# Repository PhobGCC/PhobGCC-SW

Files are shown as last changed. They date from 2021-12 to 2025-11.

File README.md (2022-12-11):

# PhobGCC

PhobGCC is an open-source Gamecube controller motherboard aiming to make an accessible and consistent controller. The key feature is the use of hall effect sensors instead of potentiometers, which eliminates a wear item. Additonally, it features notch calibration, digital snapback filtering, button remapping, and various trigger configurations.

If you are interested in making one, join the project Discord to ask questions and get the most up to date information: https://discord.gg/eNJ7xWMvxf

You can find all documentation here: https://github.com/PhobGCC/PhobGCC-doc

Board version 1.2:

Board version 1.2

Hall effect sensors:

Prototypes

Initial prototypes:

Prototypes

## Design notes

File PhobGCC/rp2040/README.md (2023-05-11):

To build PhobGCC for the RP2040:

1. Install the compiler toolchain as per the [Pico documentation](https://datasheets.raspberrypi.com/pico/getting-started-with-pico.pdf).
2. Git clone the `pico-sdk` repository from https://github.com/raspberrypi/pico-sdk
3. Check out the master branch.
4. Run `git submodule update --init` (omit `--init` if you're not doing it for the first time)
5. Export the `pico-sdk` directory as an environment variable `export PICO_SDK_PATH=[directory containing]/pico-sdk`
6. Clone the PhobGCC-SW repository.
7. Uncomment the appropriate `#include` line for your board in `../common/phobGCC.h`.
8. `cd` into the `PhobGCC/rp2040` subdirectory inside the `PhobGCC-SW` folder.
9. `mkdir build && cd build`
10. `cmake ..`
11. `make`?

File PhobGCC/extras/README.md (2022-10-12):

# Developer's Reference for Extras

This document (hopefully) intends to be a helpful guide for developers who wish to add additional features
to the PhobGCC called Extras that, while might be out of scope for normal operation, are officially supported 
and can be enabled manually by users if they uncomment out a `#define` directive and assign the Extra to one of
4 directional configurations.

# Overview

There is a loose framework for Extras written into the PhobGCC codebase for where to write your code, how to
hook your Extra into the main logic of the PhobGCC, and toggling / configuration. 

The general idea is that you write the logic for it as its own header file in the 'extras' folder while 
giving it its own namespace, write hooks to your code wrapped in `#ifdef`s in the main logic of the
PhobCC, then give function pointers for configuration and toggling your Extra to the PhobGCC 
Extras registration code in 'extras.h'.

We'll be going through all of these in this document.

# Data Structures

There's various data structures that you'll be utilizing as you write your Extra:

## Configuration Structures 

### ExtrasSlot
`ExtrasSlot` is an enum that is used as an index to reference which configuration direction slot an
Extra is using. You'll want to save a reference to which slot your configuration is using somewhere
in your Extra's header file since you'll need it to save your configuration settings.
```c++
enum ExtrasSlot{
	EXTRAS_UP,
	EXTRAS_DOWN,
	EXTRAS_LEFT,
	EXTRAS_RIGHT,
	EXTRAS_SIZE,
	EXTRAS_UNSET
};
```

### ExtrasConfig and IntOrFloat
`IntOrFloat` is a union that stores, well, either an `int` or a `float`. This is used as a part of the
Extras configuration struct `ExtrasConfig`, where each Extra gets 4 words worth of storage in the
EEPROM for storing and loading configuration settings. 
```c++
union IntOrFloat{
	int intValue;
	float floatValue;
};

struct ExtrasConfig{
	IntOrFloat config[4];
};
```

This is stored at the end of the `ControlConfig` struct which holds the general 
live configuration of the PhobGCC. 

```c++
/* ... */
	const int snapbackDefault;
	const float smoothingMin;
	const float smoothingMax;
	ExtrasConfig extras[EXTRAS_SIZE];
};
```

### Cardinals

`Cardinals` is a simple struct consisting of 4 variables, one for each direction. This is
passed in during the configuration of your Extra where each direction correlates to which
dpad button was pressed during the configuration button combo so you can handle what happens
with each direction accordingly.

```c++
struct Cardinals{
	uint8_t l : 1;
	uint8_t r : 1;
	uint8_t u : 1;
	uint8_t d : 1;
};
```

## EEPROM Setters

There's two functions you'll be using related to the configuration of your extra,
`setExtrasSettingInt` and `getExtrasSettingFloat`. These are used to write your Extra's
configuration to EEPROM so that they'll be automatically restored when the PhobGCC is
powered on after being unplugged.

```c++
void setExtrasSettingInt(const ExtrasSlot slot, const int offset, const int value);
void setExtrasSettingFloat(const ExtrasSlot slot, const int offset, const float value);
```

`slot` is the directional configuration that your Extra is 
  assigned to, you will have a reference to this in your
  Extra's header file. 
  
`offset` is a number 0-3 which determines which of the Extra's 
  4 configuration words your value will be written to. 
  
`value` is the value you're passing in to be written to EEPROM.

## Function Typedefs

There's two functions for toggling and configuring your Extra. The way to format these functions
are standardized with a `typedef` for each.

```c++
typedef bool(*ExtrasToggleFn)(IntOrFloat config[]);//Used for toggling extras
typedef void(*ExtrasConfigFn)(IntOrFloat config[], Cardinals dpad);//Used for configuring extras with the Dpad
```

### Toggling

The toggle function is called when the user is not in safe mode and uses the button combination:

* A + B + Both sticks pointed in the directional configuration

The toggle function takes in the configuration for your Extra so you can write and read from it, and returns
a `bool` that signals if you enabled (`true`) or disabled (`false`) your Extra. This return value
is used to freeze both sticks facing up-right or down-left as a visual indicator for the user
to determine if the Extra is now enabled or disabled. 

### Configuration

The config function is called when the user is not in safe mode and uses the button combination:

* A + Dpad (any direction) + Both sticks pointed in the directional configuration

The config function takes in the configuration for your Extra so you can write and read from it, but it 
also reads in the dpad as a `Cardinals` struct. In your config function, you can determine what happens depending
on what dpad button is currently being pressed.

# Writing the Hook

Depending on what you're trying to do, you'll write one or more hooks to your code's logic somewhere in
the main codebase of the PhobGCC. If you're creating some sort of new mapping or want to modify the control
sticks or analog trigger sliders, you'll probably write a hook to your code from `readSticks`. 

For example, here's the hook for the ESS Adapter Extra:

```c++
/* ... */
	//Clamp values from -125 to +125
	remappedAx = min(125, max(-125, remappedAx));
	remappedAy = min(125, max(-125, remappedAy));
	remappedCx = min(125, max(-125, remappedCx+controls.cXOffset));
	remappedCy = min(125, max(-125, remappedCy+controls.cYOffset));

	bool skipAHyst = false;
#ifdef EXTRAS_ESS
	//ESS adapter functionality for Ocarina of Time on WiiVC if enabled
	skipAHyst = ess::remap(&remappedAx, &remappedAy, controls.extras[ess::extrasEssConfigSlot].config);
#endif

	float hystVal = 0.3;
	//assign the remapped values to the button struct
	if(readA){
		if (!skipAHyst) {
/* ... */
```

Here I'm modifying the control sticks by passing them by reference to my Extra where they're
modified before logic returns back to here. 

Notice that I had to add this `skipAHyst` boolean outside of the `#ifdef`. You can add external
variables but only if needed. But ideally the only thing added is your `#ifdef` and a single
line to your header file in the 'extras' folder. 

More than likely you'll want to pass in the configuration options for your Extra as well since
the standard way to access an Extra's configuration is by passing it in from the hook where you'll
have access to `ControlConfig &controls` which contains `ExtrasConfig extras[EXTRAS_SIZE]`.

# Formatting your Extra's Header

Your Extra's header is where you have the freedom to do just about whatever you want with the
information you pass into it. There's a basic structure you'll want to follow however.

```c++
#ifndef EXTRAS_EXAMPLE_H
#define EXTRAS_EXAMPLE_H

namespace example {
  ExtrasSlot configSlot = EXTRAS_UNSET;
  
  // write your hook code here
  
  bool toggle(IntOrFloat config[]) {
    // toggle Extra and probably write enabled/disabled to EEPROM
  }

  void config(IntOrFloat config[], Cardinals dpad) {
    // config Extra and probably store it to EEPROM
  }
}

#endif //EXTRAS_EXAMPLE_H
```

Your Extra's config slot will be set from 'extras.h'. You'll use it if / when you need to save
your configuration by using the `setExtrasSettingInt` or `setExtrasSettingFloat` functions.

Again, the toggle and config functions need to follow the typdefs for `ExtrasToggleFn` and `ExtrasConfigFn`
since we'll be referencing them when we register the Extra in 'extras.h'.

# Adding your Extra to 'extras.h'

There's three things that need to be done to 'extras.h' when adding your Extra to the codebase:
* Adding a `#define` directive that can be uncommented to enable your Extra 
* Wraping the inclusion of your Extra's header file in `#ifdef`s
* Adding your Extra to the initialization function `extrasInit()`.

The first two are pretty straight forward, just add a new line under the existing Extras at the top
of the file and then just under that add your header file wrapped in the `#define` you made.

```c++
/* Plugins and extra features outside the normal scope of
 * the PhobGCC can be found here. Uncomment each #define
 * to include the features they provide in a build then
 * set the configuration slot it uses (if it needs configuration)
 * 
 */
//------------------------------------------------------
//#define EXTRAS_ESS
//#define EXTRAS_EXAMPLE <--- your new Extra
//------------------------------------------------------

#ifdef EXTRAS_ESS
#include "ess.h"
#endif

// your new Extra
#ifdef EXTRAS_EXAMPLE
#include "example.h" 
#endif
```

For the third one, you can essentially copy and paste an 
existing `#ifdef`'d blocks and modify it as needed. 

You should not add anything extra to these lines, only modify
the text and change the function references to point to the 
ones in your Extra. 

`extrasConfigAssign` takes in 3 parameters: 

* `slot` is the directional configuration slot that the users sets.
* `toggleFn` is the function pointer to your Extra's toggle function.
* `configFn` is the function pointer to your Extra's config function.

Either or both function pointers can be safely set to `NULL` if not used.

```c++
void extrasInit() {
	/*----------------------------------------------------------
	 * Configuration slots for extras, the available options are:
	 *	- EXTRAS_UP
	 *	- EXTRAS_DOWN
	 *	- EXTRAS_LEFT
	 *	- EXTRAS_RIGHT
	 * Make sure to set the slot from EXTRAS_UNSET to one of the
	 * above for the extras below if applicable!
	 */

#ifdef EXTRAS_ESS
	//-----------------------------------------
	ess::extrasEssConfigSlot = EXTRAS_UNSET;
	//-----------------------------------------
	Serial.println("Extra: Enabling ESS functionality...");
	extrasConfigAssign(ess::extrasEssConfigSlot, ess::toggle, NULL);
#endif

// your new Extra
#ifdef EXTRAS_EXAMPLE
	//-----------------------------------------
	example::configSlot = EXTRAS_UNSET;
	//-----------------------------------------
	Serial.println("Extra: Enabling Example functionality...");
	extrasConfigAssign(example::configSlot, example::toggle, example::config);
#endif

}
```

# Closing Comments

This is about it with regards to developing Extras for the PhobGCC firmware. If you have any questions
about how something works or need help figuring out how to format your code, or anything else related
to developing Extras, please stop by the Discord and ask for help. 

[PhobGCC Discord](https://discord.gg/yrpUu7mgzm)

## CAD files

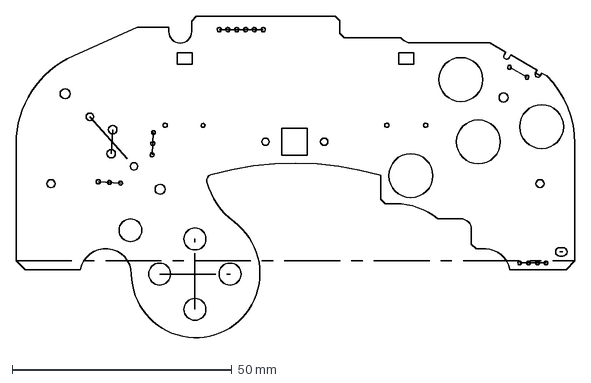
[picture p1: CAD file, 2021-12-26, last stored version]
PCB/Graphics/Board Outline.DXF
127.0 x 74.1 mm

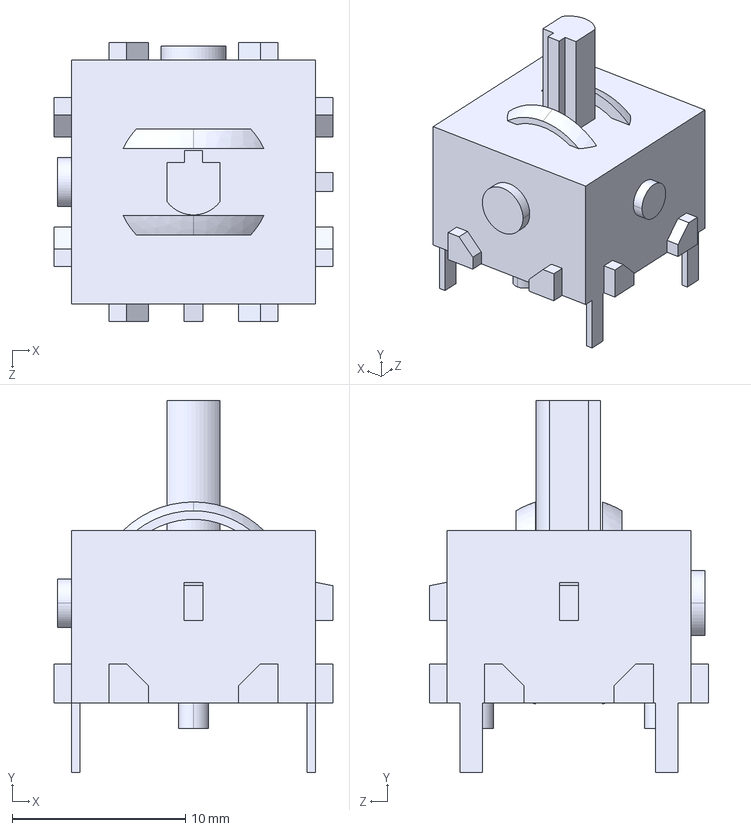
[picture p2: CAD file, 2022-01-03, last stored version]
PCB/Models/t2 Stickbox.STEP
16.1 x 21.4 x 16.1 mm

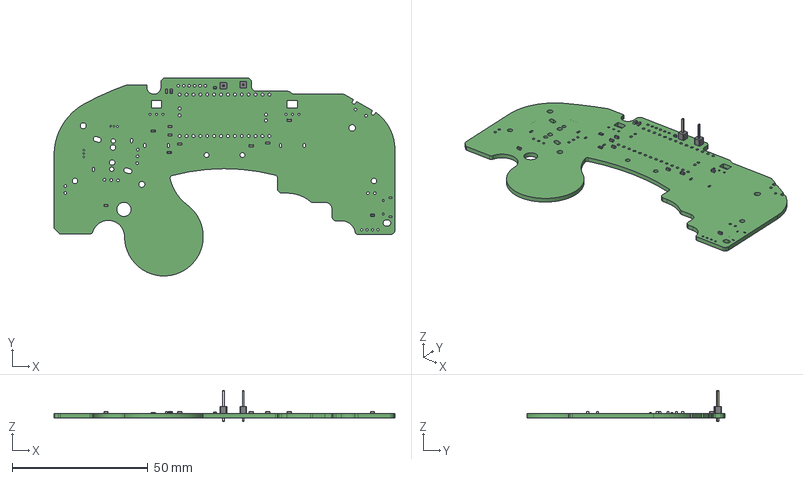
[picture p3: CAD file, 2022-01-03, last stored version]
PCB/PhobGCC.step
125.5 x 72.9 x 11.5 mm
Pin_Header_Straight_1x02_Pitch2.54mm x 2

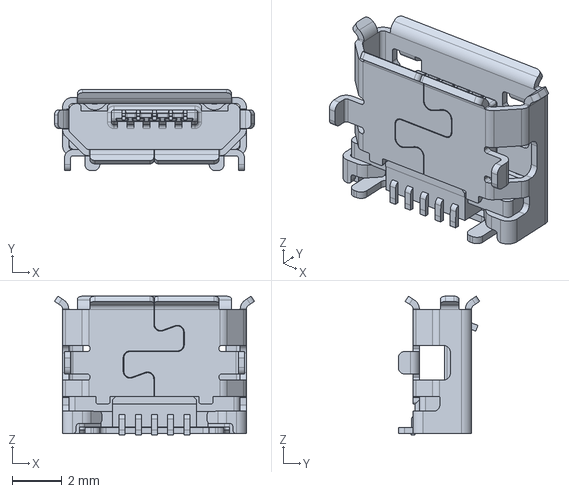
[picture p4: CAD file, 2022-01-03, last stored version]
PCB/Models/10118194c.step
8.05 x 3.27 x 5.58 mm

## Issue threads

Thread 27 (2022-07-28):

add optional auto-wake

CarVac, 2022-07-28:
it should reset any time you reset or calibrate

CarVac, 2022-08-10:
Implemented here https://github.com/PhobGCC/PhobGCC-SW/commit/e94b27e09e99a4c4f145899286b73ea4027d42db

Closed 2022-08-13.

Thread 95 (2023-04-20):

feature request: trigger trick mode

CarVac, 2023-04-20:
Should it be an offset from the startup slider position, or a fixed offset from 0 volts?

Dunno. TBD.

trstruth, 2023-09-06:
+1, would love to see something like this!

carafelix, 2023-12-01:
```.triggerConfigMax = 7,```
and
```C
case 7: //Modify Analog Trigger Starting point
			tempBtn.Ra = (uint8_t) readRa(pin, controls.rTrigInitial, 1) * shutoffRa;

			if(tempBtn.Ra < controls.rTriggerOffset){
				tempBtn.Ra = (uint8_t) 0;
			}
			break;
			```

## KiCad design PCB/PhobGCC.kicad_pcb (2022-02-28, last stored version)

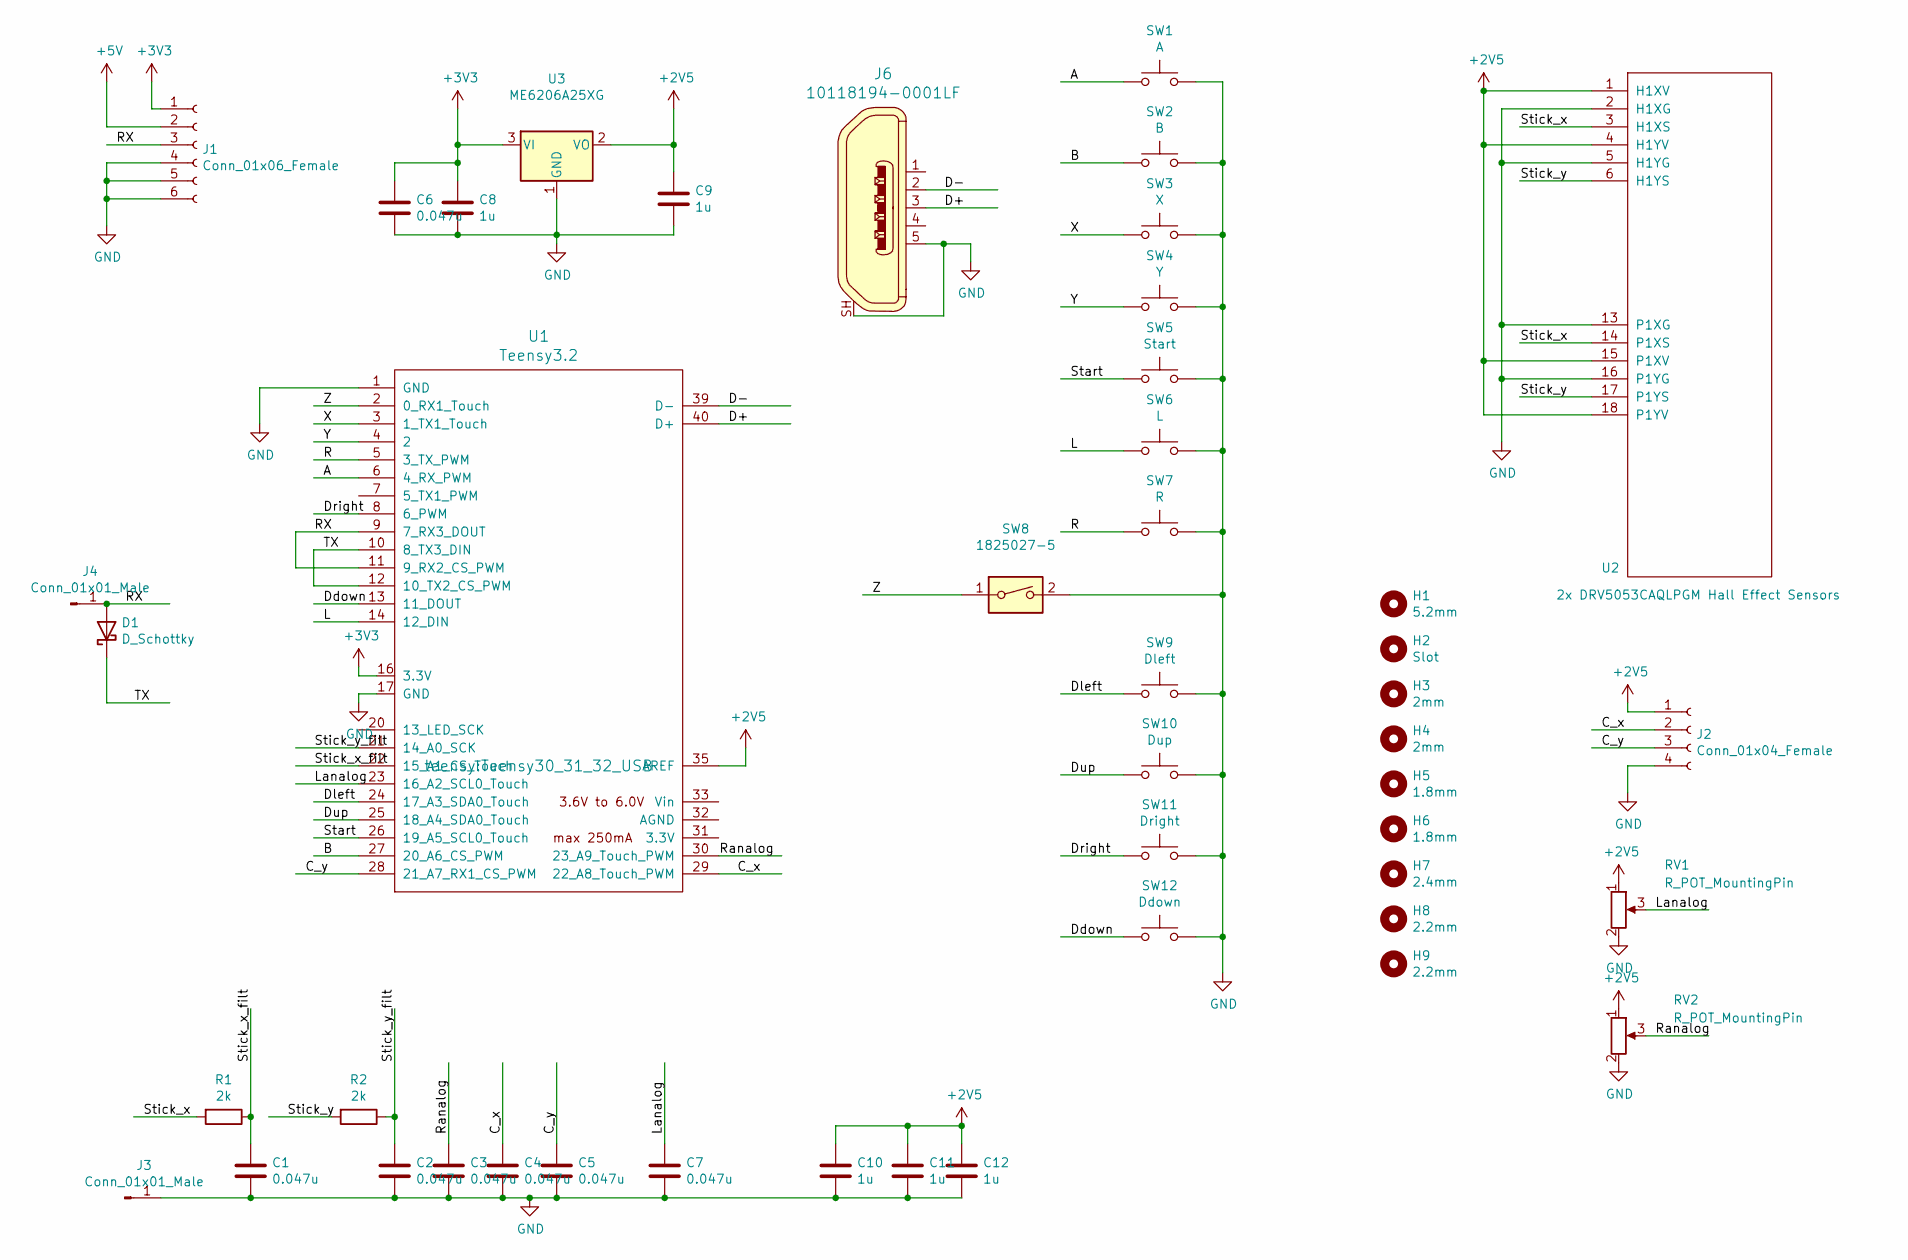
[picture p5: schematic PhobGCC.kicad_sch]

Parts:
C1, C2, C3, C4, C5, C6, C7: 0.047u; C_0603_HandSoldering; MPN 0603B222K500NT; LCSC C1604
C8, C9, C10, C11, C12: 1u; C_0603_HandSoldering; MPN CL10A105KB8NNNC; LCSC C15849
D1: D_Schottky; D_SOD-523_large_pads; Manufacturer PN SDM03U40-7; LCSC C151333
H1: 5.2mm; MountingHole_5.2mm
H2: Slot
H3, H4: 2mm; MountingHole_2.0mm
H5, H6: 1.8mm; MountingHole_1.8mm
H7: 2.4mm; MountingHole_2.4mm
H8, H9: 2.2mm; MountingHole_2.2mm
J1: Conn_01x06_Female; GCC_Header_Straight_1x06_Pitch2.00mm
J2: Conn_01x04_Female; Pin_Header_Straight_1x04_Pitch2.00mm
J3, J4: Conn_01x01_Male; PinHeader_1x01_P2.54mm_Vertical
J6: 10118194-0001LF; USB_Micro_B_Female_10118194-0001LF; MPN 10118194-0001LF; Digi-Key_PN 609-4618-1-ND
R1: 2k; R_0603_1608Metric; Manufacturer PN 0603WAF1002T5ECopy; LCSC C25804
R2: 2k; R_0603_1608Metric; MPN 0603WAF1002T5E; LCSC C25804
RV1, RV2: R_POT_MountingPin; GCC_Slider
SW1: A; ABXY_layout_small_mask
SW2: B; ABXY_layout_small_mask
SW3: X; ABXY_layout_small_mask
SW4: Y; ABXY_layout_small_mask
SW5: Start; Start_Contact
SW6: L; Pin_Header_Straight_1x02_Pitch2.54mm
SW7: R; Pin_Header_Straight_1x02_Pitch2.54mm
SW8: 1825027-5; Z_Switch_Edge
SW9: Dleft; Dpad_Contact
SW10: Dup; Dpad_Contact
SW11: Dright; Dpad_Contact
SW12: Ddown; Dpad_Contact
U1: Teensy3.2; Teensy30_31_32_USB
U2: 2x DRV5053CAQLPGM Hall Effect Sensors; GCC_Stickbox_2
U3: ME6206A25XG; SOT-23_Handsoldering; MPN ME6206A25XG; LCSC C236704

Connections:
+2V5: C9.1, C10.1, C11.1, C12.1, J2.1, RV1.1 (V+), RV2.1 (V+), U1.35 (AREF), U2.1 (H1XV), U2.4 (H1YV), U2.15 (P1XV), U2.18 (P1YV), U3.2 (VO)
+3V3: C6.1, C8.1, J1.1, U1.16 (3.3V), U3.3 (VI)
+5V: J1.2
/A: SW1.1, U1.6 (4_RX_PWM)
/B: SW2.1, U1.27 (20_A6_CS_PWM)
/C_x: C4.1, J2.2, U1.29 (22_A8_Touch_PWM)
/C_y: C5.1, J2.3, U1.28 (21_A7_RX1_CS_PWM)
/D+: J6.3, U1.40 (D+)
/D-: J6.2, U1.39 (D-)
/Ddown: SW12.1, U1.13 (11_DOUT)
/Dleft: SW9.1, U1.24 (17_A3_SDA0_Touch)
/Dright: SW11.1, U1.8 (6_PWM)
/Dup: SW10.1, U1.25 (18_A4_SDA0_Touch)
/L: SW6.1, U1.14 (12_DIN)
/Lanalog: C7.1, RV1.3 (Signal), U1.23 (16_A2_SCL0_Touch)
/R: SW7.1, U1.5 (3_TX_PWM)
/RX: D1.2 (A), J1.3, J4.1, U1.9 (7_RX3_DOUT), U1.11 (9_RX2_CS_PWM)
/Ranalog: C3.1, RV2.3 (Signal), U1.30 (23_A9_Touch_PWM)
/Start: SW5.1, U1.26 (19_A5_SCL0_Touch)
/Stick_x: R1.2, U2.3 (H1XS), U2.14 (P1XS)
/Stick_x_filt: C1.1, R1.1, U1.22 (15_A1_CS_Touch)
/Stick_y: R2.2, U2.6 (H1YS), U2.17 (P1YS)
/Stick_y_filt: C2.1, R2.1, U1.21 (14_A0_SCK)
/TX: D1.1 (K), U1.10 (8_TX3_DIN), U1.12 (10_TX2_CS_PWM)
/X: SW3.1, U1.3 (1_TX1_Touch)
/Y: SW4.1, U1.4 (2)
/Z: SW8.1, U1.2 (0_RX1_Touch)
GND: C1.2, C2.2, C3.2, C4.2, C5.2, C6.2, C7.2, C8.2, C9.2, C10.2, C11.2, C12.2, J1.4, J1.5, J1.6, J2.4, J3.1, J6.5, J6.SH, RV1.2 (GND), RV2.2 (GND), SW1.2, SW2.2, SW3.2, SW4.2, SW5.2, SW6.2, SW7.2, SW8.2, SW9.2, SW10.2, SW11.2, SW12.2, U1.1 (GND), U1.17 (GND), U2.2 (H1XG), U2.5 (H1YG), U2.13 (P1XG), U2.16 (P1YG), U3.1 (GND)

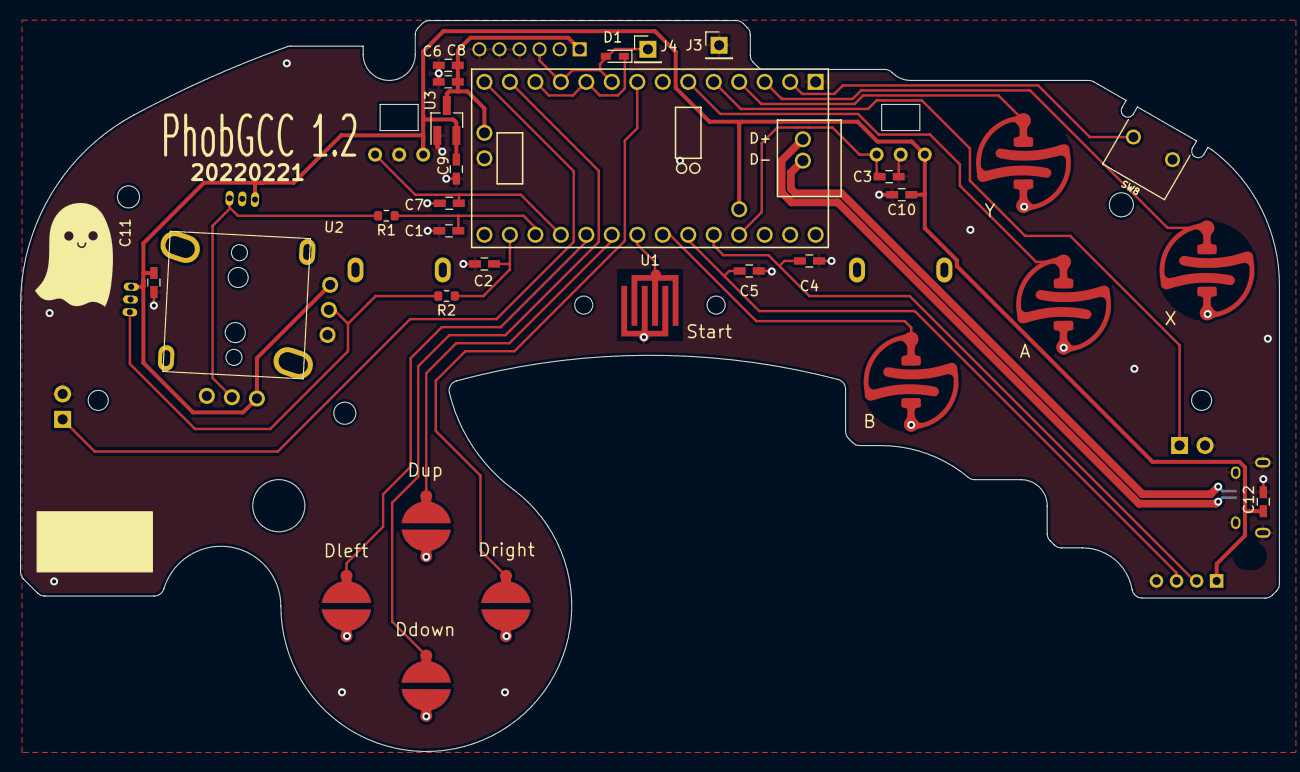
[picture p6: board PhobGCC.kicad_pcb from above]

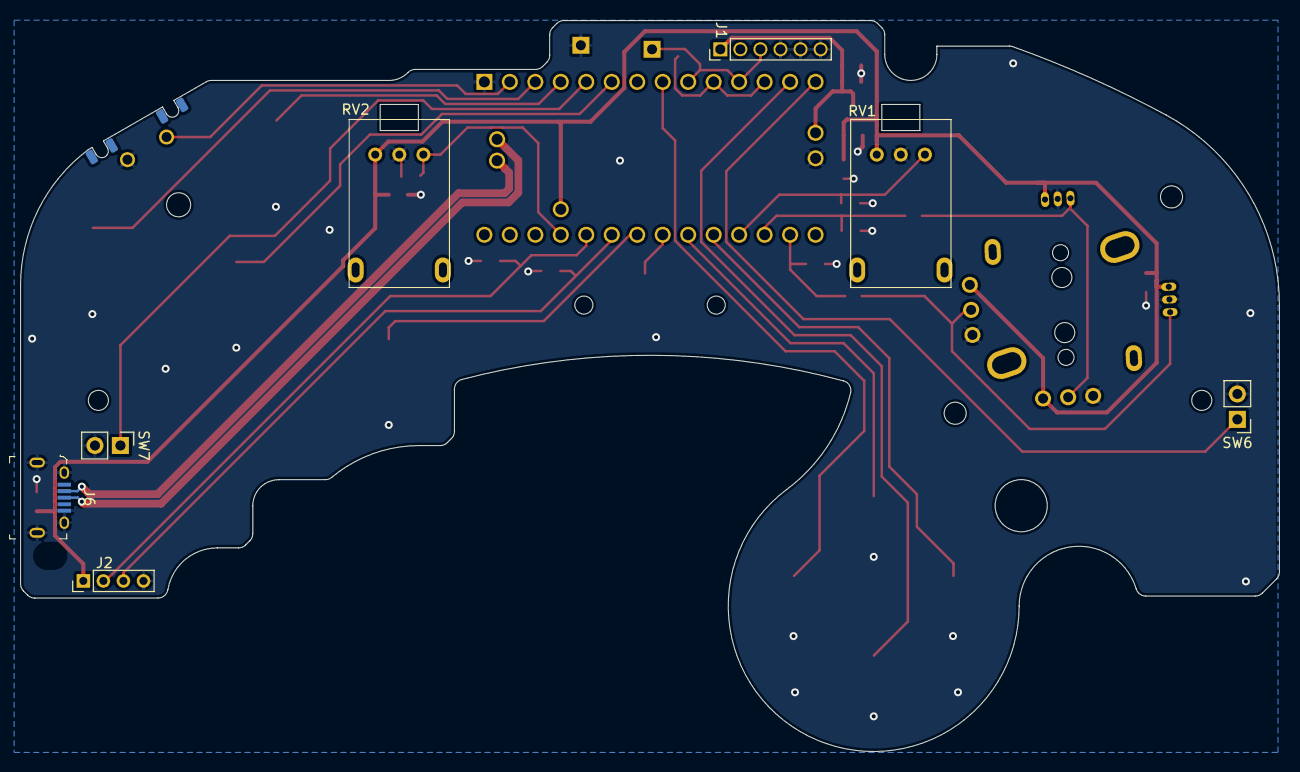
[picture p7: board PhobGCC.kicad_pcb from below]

Board: 2 copper layers, 125.5 x 72.9 mm, 46 parts (7 on the bottom side), 27 nets.

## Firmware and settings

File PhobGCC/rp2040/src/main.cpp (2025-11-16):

#include "pico/stdlib.h"
#include "pico/bootrom.h"
#include "pico/multicore.h"
#include "hardware/timer.h"
#include "hardware/pwm.h"

#include "phobGCC.h"
#include "comms/joybus.hpp"
#include "cvideo.h"
#include "cvideo_variables.h"
#include "hardware/clocks.h"

volatile bool _videoOut = false;
//Variables used by PhobVision to communicate with the event loop core
volatile bool _sync = false;
volatile uint8_t _pleaseCommit = 0;//255 = redraw please
int _currentCalStep = -1;//-1 means not calibrating
int _currentRemapStep = -1;//-1 means not remapping
bool _currentlyRaw = false;
DataCapture _dataCapture;

//This gets called by the comms library
GCReport __no_inline_not_in_flash_func(buttonsToGCReport)() {
	GCReport report = {{
		.a       = _btn.A,
		.b       = _btn.B,
		.x       = _btn.X,
		.y       = _btn.Y,
		.start   = _btn.S,
		.pad0    = 0,
		.dLeft   = _btn.Dl,
		.dRight  = _btn.Dr,
		.dDown   = _btn.Dd,
		.dUp     = _btn.Du,
		.z       = _btn.Z,
		.r       = _btn.R,
		.l       = _btn.L,
		.pad1    = 1,
		.xStick  = _btn.Ax,
		.yStick  = _btn.Ay,
		.cxStick = _btn.Cx,
		.cyStick = _btn.Cy,
		.analogL = _btn.La,
		.analogR = _btn.Ra
	}};
	return report;
}

void second_core() {

	gpio_set_function(_pinLED, GPIO_FUNC_PWM);
	uint slice_num = pwm_gpio_to_slice_num(_pinLED);
	pwm_set_wrap(slice_num, 255);
	pwm_set_chan_level(slice_num, PWM_CHAN_B, 25);
	pwm_set_enabled(slice_num, true);

	extrasInit();


	while(true) { //main event loop
		//Set up persistent storage for calibration
		static float tempCalPointsX[_noOfCalibrationPoints];
		static float tempCalPointsY[_noOfCalibrationPoints];
		static WhichStick whichStick = ASTICK;
		static NotchStatus notchStatus[_noOfNotches];
		static float notchAngles[_noOfNotches];
		static float measuredNotchAngles[_noOfNotches];
		static bool advanceCal = false;
		static bool undoCal = false;


		//when requested by the other core, commit the settings
		if(_pleaseCommit != 0) {
			if(_pleaseCommit == 1) {
				_pleaseCommit = 0;
				recomputeGains(_controls, _gains, _normGains);
				commitSettings();
			} else if(_pleaseCommit == 2) {
				_pleaseCommit = 0;
				resetDefaults(SOFT, _controls, _gains, _normGains, _aStickParams, _cStickParams);
			} else if(_pleaseCommit == 3) {
				_pleaseCommit = 0;
				resetDefaults(HARD, _controls, _gains, _normGains, _aStickParams, _cStickParams);
			} else if(_pleaseCommit == 4) {
				//Advance cal, A-stick
				_pleaseCommit = 255;
				whichStick = ASTICK;
				if(_currentCalStep == -1) {
					_currentCalStep++;
				}
				calibrationAdvance(_controls, _currentCalStep, whichStick, tempCalPointsX, tempCalPointsY, undoCal, notchAngles, notchStatus, measuredNotchAngles, _aStickParams, _cStickParams);
			} else if(_pleaseCommit == 5) {
				//Advance cal, C-stick
				_pleaseCommit = 255;
				whichStick = CSTICK;
				if(_currentCalStep == -1) {
					_currentCalStep++;
				}
				calibrationAdvance(_controls, _currentCalStep, whichStick, tempCalPointsX, tempCalPointsY, undoCal, notchAngles, notchStatus, measuredNotchAngles, _aStickParams, _cStickParams);
			} else if(_pleaseCommit == 6) {
				//undo cal
				_pleaseCommit = 255;
				calibrationUndo(_currentCalStep, whichStick, notchStatus);
			} else if(_pleaseCommit == 7) {
				//skip cal (might not actually get used?) (it's available but not shown)
				_pleaseCommit = 255;
				calibrationSkipMeasurement(_currentCalStep, whichStick, tempCalPointsX, tempCalPointsY, notchStatus, notchAngles, measuredNotchAngles, _aStickParams, _cStickParams, _controls);
			} else if(_pleaseCommit == 8) {
				_pleaseCommit = 0;
				_rumblePower = calcRumblePower(_controls.rumble);
				//rumble for 0.3 seconds
				pwm_set_gpio_level(_pinBrake, 0);
				pwm_set_gpio_level(_pinRumble, _rumblePower);
				int startTime = millis();
				int delta = 0;
				while(delta < 300) {
					delta = millis() - startTime;
				}
				pwm_set_gpio_level(_pinRumble, 0);
				pwm_set_gpio_level(_pinBrake, 255);
			} else if(_pleaseCommit == 9) {
				switch(_dataCapture.mode) {
					//make sure that we can write 200 things in a1 (clobbering a2) for longer recording
					//this is used for single-axis recording
					static_assert(&_dataCapture.a1[100] == &_dataCapture.a2[0]);
					static_assert(&_dataCapture.a1Unfilt[100] == &_dataCapture.a2Unfilt[0]);

					case CM_REACTION:
						//this expects that you initialize data capture by setting delay to 0
						_dataCapture.delay++;
						if(
								//_btn.arr[0] & 0b11110000 ||//abxy
								//_btn.arr[1] & 0b11111110 ||//dpad, lrz
								_btn.arr[0] & 0b00001111 ||//abxy
								_btn.arr[1] & 0b01111111 ||//dpad, lrz
								max(max(abs(int(_btn.Ax)-127), abs(int(_btn.Ay)-127)),
									max(abs(int(_btn.Cx)-127), abs(int(_btn.Cy)-127))) >= _dataCapture.stickThresh ||
								max(_btn.La, _btn.Ra) >= _dataCapture.triggerThresh) {
							_dataCapture.done = true;
							_pleaseCommit = 255;//end capture and display
						}
						break;
					case CM_STICK_RISE2:
						//100 points of 2-axis data
						//this begins capturing data immediately in a rolling buffer,
						//and on detecting a rising edge it begins recording
						//this records the starting point only the first time, then it sets begin
						static int x0;
						static int y0;

						if(!_dataCapture.begin && !_dataCapture.done) {
							_dataCapture.begin = true;
							_dataCapture.done = false;
							_dataCapture.startIndex = 0;
							_dataCapture.endIndex = 255;//when it triggers, we freeze startIndex and start counting up here
							if(_dataCapture.captureStick == ASTICK) {
								x0 = _raw.axUnfiltered;
								y0 = _raw.ayUnfiltered;
								_dataCapture.a1[_dataCapture.startIndex] = _btn.Ax;
								_dataCapture.a2[_dataCapture.startIndex] = _btn.Ay;
								_dataCapture.a1Unfilt[_dataCapture.startIndex] = (uint8_t) (_raw.axUnfiltered+_floatOrigin);
								_dataCapture.a2Unfilt[_dataCapture.startIndex] = (uint8_t) (_raw.ayUnfiltered+_floatOrigin);
							} else {
								x0 = _raw.cxUnfiltered;
								y0 = _raw.cyUnfiltered;
								_dataCapture.a1[_dataCapture.startIndex] = _btn.Cx;
								_dataCapture.a2[_dataCapture.startIndex] = _btn.Cy;
								_dataCapture.a1Unfilt[_dataCapture.startIndex] = (uint8_t) (_raw.cxUnfiltered+_floatOrigin);
								_dataCapture.a2Unfilt[_dataCapture.startIndex] = (uint8_t) (_raw.cyUnfiltered+_floatOrigin);
							}
							//                                                                   syxba                       lrz
							_dataCapture.abxyszrl[_dataCapture.startIndex] = (_btn.arr[0] & 0b00011111) | ((_btn.arr[1] & 0b01110000) << 1);
						} else {
							if(_dataCapture.endIndex == 255) {
								//not triggered yet
								//increment startIndex
								_dataCapture.startIndex = (_dataCapture.startIndex+1) % 100;
								//record
								if(_dataCapture.captureStick == ASTICK) {
									_dataCapture.a1[_dataCapture.startIndex] = _btn.Ax;
									_dataCapture.a2[_dataCapture.startIndex] = _btn.Ay;
									_dataCapture.a1Unfilt[_dataCapture.startIndex] = (uint8_t) (_raw.axUnfiltered+_floatOrigin);
									_dataCapture.a2Unfilt[_dataCapture.startIndex] = (uint8_t) (_raw.ayUnfiltered+_floatOrigin);
									//if it's not triggered, do nothing further
									//if it's triggered, set endIndex to startIndex+1
									int diffX = abs(int(_raw.axUnfiltered) - x0);
									int diffY = abs(int(_raw.ayUnfiltered) - y0);
									if(diffX > _dataCapture.stickThresh || diffY > _dataCapture.stickThresh) {
										_dataCapture.endIndex = (_dataCapture.startIndex+1) % 100;
									}
								} else {
									_dataCapture.a1[_dataCapture.startIndex] = _btn.Cx;
									_dataCapture.a2[_dataCapture.startIndex] = _btn.Cy;
									_dataCapture.a1Unfilt[_dataCapture.startIndex] = (uint8_t) (_raw.cxUnfiltered+_floatOrigin);
									_dataCapture.a2Unfilt[_dataCapture.startIndex] = (uint8_t) (_raw.cyUnfiltered+_floatOrigin);
									//if it's not triggered, do nothing further
									//if it's triggered, set endIndex to startIndex+1
									int diffX = abs(int(_raw.cxUnfiltered) - x0);
									int diffY = abs(int(_raw.cyUnfiltered) - y0);
									if(diffX > _dataCapture.stickThresh || diffY > _dataCapture.stickThresh) {
										_dataCapture.endIndex = (_dataCapture.startIndex+1) % 100;
									}
								}
								//                                                                   syxba                       lrz
								_dataCapture.abxyszrl[_dataCapture.startIndex] = (_btn.arr[0] & 0b00011111) | ((_btn.arr[1] & 0b01110000) << 1);
							} else if(_dataCapture.endIndex != _dataCapture.startIndex) {
								//triggered
								//record
								if(_dataCapture.captureStick == ASTICK) {
									_dataCapture.a1[_dataCapture.endIndex] = _btn.Ax;
									_dataCapture.a2[_dataCapture.endIndex] = _btn.Ay;
									_dataCapture.a1Unfilt[_dataCapture.endIndex] = (uint8_t) (_raw.axUnfiltered+_floatOrigin);
									_dataCapture.a2Unfilt[_dataCapture.endIndex] = (uint8_t) (_raw.ayUnfiltered+_floatOrigin);
								} else {
									_dataCapture.a1[_dataCapture.endIndex] = _btn.Cx;
									_dataCapture.a2[_dataCapture.endIndex] = _btn.Cy;
									_dataCapture.a1Unfilt[_dataCapture.endIndex] = (uint8_t) (_raw.cxUnfiltered+_floatOrigin);
									_dataCapture.a2Unfilt[_dataCapture.endIndex] = (uint8_t) (_raw.cyUnfiltered+_floatOrigin);
								}
								//                                                                 syxba                       lrz
								_dataCapture.abxyszrl[_dataCapture.endIndex] = (_btn.arr[0] & 0b00011111) | ((_btn.arr[1] & 0b01110000) << 1);
								//increment endIndex
								_dataCapture.endIndex = (_dataCapture.endIndex+1) % 100;
							} else {
								//done
								_dataCapture.done = true;
								_pleaseCommit = 255;//end capture and display
							}
						}
						break;
					case CM_STICK_RISE:
						//200 points of single-axis data
						//based on the raw unfiltered values hitting >= 23
						//it should record for 150 ms after detection (saving 50 from before detection)

						//prep
						//expect data to be prepped already
						//begin = false
						//triggered = false
						//done = false
						//startIndex = 0
						//endIndex = 0

						//record data continuously if not done
						//actually, if it's done, it should never reach this
						if(_dataCapture.captureStick == ASTICK && _dataCapture.whichAxis == XAXIS) {
							_dataCapture.a1[_dataCapture.endIndex] = _btn.Ax;
							_dataCapture.a1Unfilt[_dataCapture.endIndex] = (uint8_t) (_raw.axUnfiltered+_floatOrigin);
						} else if(_dataCapture.captureStick == ASTICK && _dataCapture.whichAxis == YAXIS) {
							_dataCapture.a1[_dataCapture.endIndex] = _btn.Ay;
							_dataCapture.a1Unfilt[_dataCapture.endIndex] = (uint8_t) (_raw.ayUnfiltered+_floatOrigin);
						} else if(_dataCapture.captureStick == CSTICK && _dataCapture.whichAxis == XAXIS) {
							_dataCapture.a1[_dataCapture.endIndex] = _btn.Cx;
							_dataCapture.a1Unfilt[_dataCapture.endIndex] = (uint8_t) (_raw.cxUnfiltered+_floatOrigin);
						} else {//if(_dataCapture.captureStick == CSTICK && _dataCapture.whichAxis == YAXIS)
							_dataCapture.a1[_dataCapture.endIndex] = _btn.Cy;
							_dataCapture.a1Unfilt[_dataCapture.endIndex] = (uint8_t) (_raw.cyUnfiltered+_floatOrigin);
						}

						//check for initial waiting state
						//in this case, we want the stick's raw value to be out of the deadzone
						if(!_dataCapture.begin && !_dataCapture.done) {
							if(_dataCapture.captureStick == ASTICK && _dataCapture.whichAxis == XAXIS) {
								if(fabs(_raw.axUnfiltered) >= 23) {
									_dataCapture.begin = true;
									_dataCapture.startIndex = (_dataCapture.endIndex+150) % 200;
								}
							} else if(_dataCapture.captureStick == ASTICK && _dataCapture.whichAxis == YAXIS) {
								if(fabs(_raw.ayUnfiltered) >= 23) {
									_dataCapture.begin = true;
									_dataCapture.startIndex = (_dataCapture.endIndex+150) % 200;
								}
							} else if(_dataCapture.captureStick == CSTICK && _dataCapture.whichAxis == XAXIS) {
								if(fabs(_raw.cxUnfiltered) >= 23) {
									_dataCapture.begin = true;
									_dataCapture.startIndex = (_dataCapture.endIndex+150) % 200;
								}
							} else {//if(_dataCapture.captureStick == CSTICK && _dataCapture.whichAxis == YAXIS)
								if(fabs(_raw.cyUnfiltered) >= 23) {
									_dataCapture.begin = true;
									_dataCapture.startIndex = (_dataCapture.endIndex+150) % 200;
								}
							}
						}


						//stop if done
						if(_dataCapture.begin && _dataCapture.startIndex == _dataCapture.endIndex) {
							//calculate the dashback chance
							//see how many ms were spent in the tilt zone, and divide by 1 frame duration
							int counter = 0;
							for(int i = 0; i < 200; i++) {
								if(fabs(_dataCapture.a1[(i+_dataCapture.startIndex+1) % 200]-_intOrigin) >= 23) {
									if(fabs(_dataCapture.a1[(i+_dataCapture.startIndex+1) % 200]-_intOrigin) >= 64) {
										break;
									}
									counter++;
								}
							}
							_dataCapture.percents[0] = fmax(0, (1 - (counter/16.666667f))*100);

							//calculate ucf dashback percent
							//ucf dashback has a two frame window but the stick must have moved 75 units
							counter = 0;
							//try each poll offset; err on the short side
							for(int offset = 0; offset < 16; offset++) {
								for(int i = offset; i < (200-32); i += 16) {
									bool dashback = false;
									const int waitIndex = (i + _dataCapture.startIndex+1) % 200;
									const int vanIndex = (i + _dataCapture.startIndex+1+16) % 200;
									const int ucfIndex = (i + _dataCapture.startIndex+1+32) % 200;
									const int waitData = abs(_dataCapture.a1[waitIndex] - _intOrigin);
									const int vanData = abs(_dataCapture.a1[vanIndex] - _intOrigin);
									const int ucfData = abs(_dataCapture.a1[ucfIndex] - _intOrigin);
									if(waitData < 23 && vanData >= 64) {
										dashback = true;
									}
									if(waitData < 23 && ucfData >= 64 && ucfData-waitData > 75) {
										dashback = true;
									}
									if(dashback) {
										counter++;
									}
								}
							}
							const float ucfDB = fmax(0, fmin(100, counter*100/16.0f));
							//never want ucf % to read less than vanilla
							//it would sometimes be like 4% lower, because we were conservative here
							_dataCapture.percents[1] = fmax(_dataCapture.percents[0], ucfDB);

							//clean up
							_dataCapture.done = true;
							_pleaseCommit = 255;//end capture and display
						}

						//advance to next index to record
						_dataCapture.endIndex = (_dataCapture.endIndex+1) % 200;
						break;
					case CM_STICK_FALL:
						//single-axis
						//based on the raw unfiltered values falling from >70 to 0 in <30 ms
						//it should record for 150 ms after detection (saving 50 from before detection)

						//prep
						//expect data to be prepped already
						//begin = false
						//triggered = false
						//done = false
						//startIndex = 0
						//endIndex = 0

						//record data continuously if not done
						//actually, if it's done, it should never reach this
						if(_dataCapture.captureStick == ASTICK && _dataCapture.whichAxis == XAXIS) {
							_dataCapture.a1[_dataCapture.endIndex] = _btn.Ax;
							_dataCapture.a1Unfilt[_dataCapture.endIndex] = (uint8_t) (_raw.axUnfiltered+_floatOrigin);
						} else if(_dataCapture.captureStick == ASTICK && _dataCapture.whichAxis == YAXIS) {
							_dataCapture.a1[_dataCapture.endIndex] = _btn.Ay;
							_dataCapture.a1Unfilt[_dataCapture.endIndex] = (uint8_t) (_raw.ayUnfiltered+_floatOrigin);
						} else if(_dataCapture.captureStick == CSTICK && _dataCapture.whichAxis == XAXIS) {
							_dataCapture.a1[_dataCapture.endIndex] = _btn.Cx;
							_dataCapture.a1Unfilt[_dataCapture.endIndex] = (uint8_t) (_raw.cxUnfiltered+_floatOrigin);
						} else {//if(_dataCapture.captureStick == CSTICK && _dataCapture.whichAxis == YAXIS)
							_dataCapture.a1[_dataCapture.endIndex] = _btn.Cy;
							_dataCapture.a1Unfilt[_dataCapture.endIndex] = (uint8_t) (_raw.cyUnfiltered+_floatOrigin);
						}

						//check for initial waiting state
						//in this case, we want the stick's raw value to be >=80
						if(!_dataCapture.begin && !_dataCapture.triggered && !_dataCapture.done) {
							if(_dataCapture.captureStick == ASTICK && _dataCapture.whichAxis == XAXIS) {
								if(fabs(_raw.axUnfiltered) >= 80) {
									_dataCapture.begin = true;
								}
							} else if(_dataCapture.captureStick == ASTICK && _dataCapture.whichAxis == YAXIS) {
								if(fabs(_raw.ayUnfiltered) >= 80) {
									_dataCapture.begin = true;
								}
							} else if(_dataCapture.captureStick == CSTICK && _dataCapture.whichAxis == XAXIS) {
								if(fabs(_raw.cxUnfiltered) >= 80) {
									_dataCapture.begin = true;
								}
							} else {//if(_dataCapture.captureStick == CSTICK && _dataCapture.whichAxis == YAXIS)
								if(fabs(_raw.cyUnfiltered) >= 80) {
									_dataCapture.begin = true;
								}
							}
						}

						//check for secondary trigger state
						//if the trigger has now dropped to less than 23 (in the deadzone)
						if(_dataCapture.begin && !_dataCapture.triggered && !_dataCapture.done) {
							if(_dataCapture.captureStick == ASTICK && _dataCapture.whichAxis == XAXIS) {
								if(fabs(_raw.axUnfiltered) < 23) {
									_dataCapture.triggered = true;
									_dataCapture.startIndex = (_dataCapture.endIndex+150) % 200;
								}
							} else if(_dataCapture.captureStick == ASTICK && _dataCapture.whichAxis == YAXIS) {
								if(fabs(_raw.ayUnfiltered) < 23) {
									_dataCapture.triggered = true;
									_dataCapture.startIndex = (_dataCapture.endIndex+150) % 200;
								}
							} else if(_dataCapture.captureStick == CSTICK && _dataCapture.whichAxis == XAXIS) {
								if(fabs(_raw.cxUnfiltered) < 23) {
									_dataCapture.triggered = true;
									_dataCapture.startIndex = (_dataCapture.endIndex+150) % 200;
								}
							} else {//if(_dataCapture.captureStick == CSTICK && _dataCapture.whichAxis == YAXIS)
								if(fabs(_raw.cyUnfiltered) < 23) {
									_dataCapture.triggered = true;
									_dataCapture.startIndex = (_dataCapture.endIndex+150) % 200;
								}
							}
						}
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
int main() {
	//set the clock speed to 125 kHz
	//the comms library needs this clockspeed
	//it's actually the default so we don't need to
	//set_sys_clock_khz(1000*_us, true);

	//debug stuff
#if (DEBUG_ENABLED)
	stdio_init_all();
#endif

	//Read settings; true = don't lock out the core because running it on core 1 will freeze
	const int numberOfNaN = readEEPROM(_controls, _gains, _normGains, _aStickParams, _cStickParams, true);
	if(numberOfNaN > 10){//by default it seems 16 end up unitialized on pico
		resetDefaults(FACTORY, _controls, _gains, _normGains, _aStickParams, _cStickParams, true);
		readEEPROM(_controls, _gains, _normGains, _aStickParams, _cStickParams, true);
	}

	setPinModes();

	Pins pinList {//not actually necessary for any of the rp2040 read functions
		.pinLa = 0,
		.pinRa = 0,
		.pinL  = 0,
		.pinR  = 0,
		.pinAx = 0,
		.pinAy = 0,
		.pinCx = 0,
		.pinCy = 0,
		.pinRX = 0,
		.pinTX = 0,
		.pinDr = 0,
		.pinDu = 0,
		.pinDl = 0,
		.pinDd = 0,
		.pinX  = 0,
		.pinY  = 0,
		.pinA  = 0,
		.pinB  = 0,
		.pinZ  = 0,
		.pinS  = 0
	};

	_btn.A      =0;
	_btn.B      =0;
	_btn.X      =0;
	_btn.Y      =0;
	_btn.S      =0;
	_btn.orig   =0;
	_btn.errL   =0;
	_btn.errS   =0;
	_btn.Dl     =0;
	_btn.Dr     =0;
	_btn.Dd     =0;
	_btn.Du     =0;
	_btn.Z      =0;
	_btn.R      =0;
	_btn.L      =0;
	_btn.high   =1;
	_btn.Ax     =127;
	_btn.Ay     =127;
	_btn.Cx     =127;
	_btn.Cy     =127;
	_btn.La     =0;
	_btn.Ra     =0;
	_btn.magic1 =0;
	_btn.magic2 =0;

	_raw.axRaw = 0;
	_raw.ayRaw = 0;
	_raw.cxRaw = 0;
	_raw.cyRaw = 0;
	_raw.axUnfiltered = 0;
	_raw.ayUnfiltered = 0;
	_raw.cxUnfiltered = 0;
	_raw.cyUnfiltered = 0;

	_dataCapture.mode = CM_NULL;
	_dataCapture.triggerStick = ASTICK;
	_dataCapture.captureStick = ASTICK;
	_dataCapture.begin = false;
	_dataCapture.done = true;
	_dataCapture.delay = 0;
	_dataCapture.stickThresh = 23;
	_dataCapture.triggerThresh = 49;
	_dataCapture.startIndex = 0;
	_dataCapture.endIndex = 0;
	_dataCapture.viewIndex = 0;

	//measure the trigger values for trigger tricking
	initializeButtons(_pinList, _btn, _controls.lTrigInitial, _controls.rTrigInitial);

	//Read buttons on startup to determine what mode to begin in
	readButtons(_pinList, _hardware);

	if(_hardware.S) { //hold start on powerup for BOOTSEL
		reset_usb_boot(0, 0);
	}

	if(_hardware.Z) { //hold Z on powerup for PhobVision
		_videoOut = true;
		set_sys_clock_khz(1000*250, true);//overclock to 250 khz, to alleviate performance issues
	}

	//delay for 20 milliseconds, should help with cubstraption
	const uint32_t lastMicros = micros();
	bool toggle = false;
	while(micros() - lastMicros < 20'000) {
		gpio_put(_pinDac0, toggle);
		toggle = !toggle;
	}

	multicore_lockout_victim_init();

	multicore_launch_core1(second_core);

	//Run comms unless Z is held while plugging in
	if(_hardware.Z) {
#ifdef BUILD_DEV
		const int version = -SW_VERSION;
#else //BUILD_DEV
		const int version = SW_VERSION;
#endif //BUILD_DEV
		videoOut(_pinDac0, _btn, _hardware, _raw, _controls, _aStickParams, _cStickParams, _dataCapture, _sync, _pleaseCommit, _currentCalStep, _currentRemapStep, version);
	} else {
		enterMode(_pinTX,
				_pinRumble,
				_pinBrake,
				_rumblePower,
				buttonsToGCReport);
	}

}

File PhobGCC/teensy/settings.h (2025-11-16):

#ifndef SETTINGS_H
#define SETTINGS_H

#include <EEPROM.h>

#include "../common/stick.h"
#include "../common/structsAndEnums.h"

//Reimplement all the functions in this header for each platform.
//Include the appropriate one in each per-board file.

namespace Eeprom {
	//index values to store data into eeprom
	const int _bytesPerUint8 = 1;
	const int _bytesPerFloat = 4;
	const int _eepromAPointsX = 0;
	const int _eepromAPointsY = _eepromAPointsX+_noOfCalibrationPoints*_bytesPerFloat;
	const int _eepromCPointsX = _eepromAPointsY+_noOfCalibrationPoints*_bytesPerFloat;
	const int _eepromCPointsY = _eepromCPointsX+_noOfCalibrationPoints*_bytesPerFloat;
	const int _eepromxSnapback = _eepromCPointsY+_noOfCalibrationPoints*_bytesPerFloat;
	const int _eepromySnapback = _eepromxSnapback+_bytesPerFloat;
	const int _eepromJump = _eepromySnapback+_bytesPerFloat;// not used
	const int _eepromANotchAngles = _eepromJump+_bytesPerFloat;
	const int _eepromCNotchAngles = _eepromANotchAngles+_noOfNotches*_bytesPerFloat;
	const int _eepromLToggle = _eepromCNotchAngles+_noOfNotches*_bytesPerFloat;
	const int _eepromRToggle = _eepromLToggle+_bytesPerFloat;
	const int _eepromcXOffset = _eepromRToggle+_bytesPerFloat;
	const int _eepromcYOffset = _eepromcXOffset+_bytesPerFloat;
	const int _eepromxSmoothing = _eepromcYOffset+_bytesPerFloat;
	const int _eepromySmoothing = _eepromxSmoothing+_bytesPerFloat;
	const int _eepromLOffset = _eepromySmoothing+_bytesPerFloat;
	const int _eepromROffset = _eepromLOffset+_bytesPerFloat;
	const int _eepromCxSmoothing = _eepromROffset+_bytesPerFloat;
	const int _eepromCySmoothing = _eepromCxSmoothing+_bytesPerFloat;
	const int _eepromRumble = _eepromCySmoothing+_bytesPerFloat;
	const int _eepromAutoInit = _eepromRumble+_bytesPerFloat;
	const int _eepromAxWaveshaping = _eepromAutoInit+_bytesPerFloat;
	const int _eepromAyWaveshaping = _eepromAxWaveshaping+_bytesPerFloat;
	const int _eepromCxWaveshaping = _eepromAyWaveshaping+_bytesPerFloat;
	const int _eepromCyWaveshaping = _eepromCxWaveshaping+_bytesPerFloat;
	const int _eepromExtrasUp = _eepromCyWaveshaping+_bytesPerFloat;
	const int _eepromExtrasDown = _eepromExtrasUp+_bytesPerFloat*4;
	const int _eepromExtrasLeft = _eepromExtrasDown+_bytesPerFloat*4;
	const int _eepromExtrasRight = _eepromExtrasLeft+_bytesPerFloat*4;
	const int _eepromSchema = _eepromExtrasRight+_bytesPerFloat*4;
	const int _eepromAstickCardinalSnapping = _eepromSchema+_bytesPerFloat;
	const int _eepromCstickCardinalSnapping = _eepromAstickCardinalSnapping+_bytesPerFloat;
	const int _eepromAstickAnalogScaler = _eepromCstickCardinalSnapping+_bytesPerFloat;
	const int _eepromCstickAnalogScaler =_eepromAstickAnalogScaler+_bytesPerFloat;
	const int _eepromTournamentToggle = _eepromCstickAnalogScaler+_bytesPerFloat;
	const int _eepromARemap = _eepromTournamentToggle+_bytesPerUint8;
	const int _eepromBRemap = _eepromARemap+_bytesPerUint8;
	const int _eepromDRemap = _eepromBRemap+_bytesPerUint8;
	const int _eepromLRemap = _eepromDRemap+_bytesPerUint8;
	const int _eepromRRemap = _eepromLRemap+_bytesPerUint8;
	const int _eepromXRemap = _eepromRRemap+_bytesPerUint8;
	const int _eepromYRemap = _eepromXRemap+_bytesPerUint8;
	const int _eepromZRemap = _eepromYRemap+_bytesPerUint8;
	//const int _nextSetting = _eepromZRemap+bytesPerFloat;
};

/*
JumpConfig getJumpSetting() {
	JumpConfig output;
	EEPROM.get(Eeprom::_eepromJump, output);
	return output;
};
*/

void getRemapSetting(
		uint8_t &aRemap,
		uint8_t &bRemap,
		uint8_t &dRemap,
		uint8_t &lRemap,
		uint8_t &rRemap,
		uint8_t &xRemap,
		uint8_t &yRemap,
		uint8_t &zRemap) {
	EEPROM.get(Eeprom::_eepromARemap, aRemap);
	EEPROM.get(Eeprom::_eepromBRemap, bRemap);
	EEPROM.get(Eeprom::_eepromDRemap, dRemap);
	EEPROM.get(Eeprom::_eepromLRemap, lRemap);
	EEPROM.get(Eeprom::_eepromRRemap, rRemap);
	EEPROM.get(Eeprom::_eepromXRemap, xRemap);
	EEPROM.get(Eeprom::_eepromYRemap, yRemap);
	EEPROM.get(Eeprom::_eepromZRemap, zRemap);
}

/*
void setJumpSetting(const JumpConfig jump) {
	EEPROM.put(Eeprom::_eepromJump, jump);
};
*/

void setRemapSetting(
		const uint8_t aRemap,
		const uint8_t bRemap,
		const uint8_t dRemap,
		const uint8_t lRemap,
		const uint8_t rRemap,
		const uint8_t xRemap,
		const uint8_t yRemap,
		const uint8_t zRemap) {
	EEPROM.put(Eeprom::_eepromARemap, aRemap);
	EEPROM.put(Eeprom::_eepromBRemap, bRemap);
	EEPROM.put(Eeprom::_eepromDRemap, dRemap);
	EEPROM.put(Eeprom::_eepromLRemap, lRemap);
	EEPROM.put(Eeprom::_eepromRRemap, rRemap);
	EEPROM.put(Eeprom::_eepromXRemap, xRemap);
	EEPROM.put(Eeprom::_eepromYRemap, yRemap);
	EEPROM.put(Eeprom::_eepromZRemap, zRemap);
}

int getLSetting() {
	int output;
	EEPROM.get(Eeprom::_eepromLToggle, output);
	return output;
};

void setLSetting(const int L) {
	EEPROM.put(Eeprom::_eepromLToggle, L);
};

int getRSetting() {
	int output;
	EEPROM.get(Eeprom::_eepromRToggle, output);
	return output;
};

void setRSetting(const int R) {
	EEPROM.put(Eeprom::_eepromRToggle, R);
};
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

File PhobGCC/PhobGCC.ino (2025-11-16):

//This software uses bits of code from GoodDoge's Dogebawx project, which was the initial starting point: https://github.com/DogeSSBM/DogeBawx

#include <math.h>

#include "common/phobGCC.h"

extern "C" uint32_t set_arm_clock(uint32_t frequency);

void setup() {
    serialSetup();
	Serial.print("Software version 0.");
	Serial.println(SW_VERSION);
#ifdef BUILD_DEV
	Serial.println("This is not a stable version");
#endif

#ifdef TEENSY4_0
	//Force-underclock Teensy 4 to 150 MHz to lower power draw.
	//set_arm_clock(150'000'000);
	//for some reason, 150 MHz doesn't work with the new comms code. 300 seems to be enough.
	set_arm_clock(300'000'000);
#endif //TEENSY4_0

	const int numberOfNaN = readEEPROM(_controls, _gains, _normGains, _aStickParams, _cStickParams);
	Serial.print("Number of NaN in EEPROM: ");
	Serial.println(numberOfNaN);
	if(numberOfNaN > 10){//by default it seems 16 end up uninitialized on Teensy 4
		resetDefaults(FACTORY, _controls, _gains, _normGains, _aStickParams, _cStickParams);//do reset sticks
		readEEPROM(_controls, _gains, _normGains, _aStickParams, _cStickParams);
	}

	//set some of the unused values in the message response
	_btn.errS = 0;
	_btn.errL = 0;
	_btn.orig = 0;
	_btn.high = 1;

    setPinModes();

    ADCSetup(adc, _ADCScale, _ADCScaleFactor);

	//measure the trigger values for trigger tricking
	initializeButtons(_pinList, _btn, _controls.lTrigInitial, _controls.rTrigInitial);
	//set the origin response before the sticks have been touched
	//it will never be changed again after this

	//start up user-enabled extras
	extrasInit();

	commsSetup(_btn);
}

void loop() {
	static bool running = false;

	//check if we should be reporting values yet
	if((_hardware.B || _controls.autoInit) && !running){
		Serial.println("Starting to report values");
		running=true;
	}

	static int currentCalStep = -1;//-1 means not calibrating
	static int currentRemapStep = -1;//-1 means not remapping
	static bool currentlyRaw = false;

	//Set up persistent storage for calibration
	static float tempCalPointsX[_noOfCalibrationPoints];
	static float tempCalPointsY[_noOfCalibrationPoints];
	static WhichStick whichStick = ASTICK;
	static NotchStatus notchStatus[_noOfNotches];
	static float notchAngles[_noOfNotches];
	static float measuredNotchAngles[_noOfNotches];

	//read the controllers buttons
	processButtons(_pinList, _btn, _hardware, _controls, _gains, _normGains, currentCalStep, currentRemapStep, currentlyRaw, running, tempCalPointsX, tempCalPointsY, whichStick, notchStatus, notchAngles, measuredNotchAngles, _aStickParams, _cStickParams);

	//check to see if we are calibrating
	if(currentCalStep >= 0){
		if(whichStick == ASTICK){
			if(currentCalStep >= _noOfCalibrationPoints){//adjust notch angles
				adjustNotch(currentCalStep, _dT, ASTICK, measuredNotchAngles, notchAngles, notchStatus, _btn, _hardware);
				if(_hardware.Y || _hardware.X || _hardware.B){//only run this if the notch was adjusted
					//clean full cal points again, feeding updated angles in
					float cleanedPointsX[_noOfNotches+1];
					float cleanedPointsY[_noOfNotches+1];
					float notchPointsX[_noOfNotches+1];
					float notchPointsY[_noOfNotches+1];
					cleanCalPoints(tempCalPointsX, tempCalPointsY, notchAngles, cleanedPointsX, cleanedPointsY, notchPointsX, notchPointsY, notchStatus);
					//linearize again
					linearizeCal(cleanedPointsX, cleanedPointsY, cleanedPointsX, cleanedPointsY, _aStickParams);
					//notchCalibrate again to update the affine transform
					notchCalibrate(cleanedPointsX, cleanedPointsY, notchPointsX, notchPointsY, _noOfNotches, _aStickParams);
				}
			}else{//just show desired stick position
				displayNotch(currentCalStep, true, _notchAngleDefaults, _btn);
			}
			readSticks(true,false, _btn, _pinList, _raw, _hardware, _controls, _normGains, _aStickParams, _cStickParams, _dT, currentCalStep, false);
		}
		else{//WHICHSTICK == CSTICK
			if(currentCalStep >= _noOfCalibrationPoints){//adjust notch angles
				adjustNotch(currentCalStep, _dT, CSTICK, measuredNotchAngles, notchAngles, notchStatus, _btn, _hardware);
				if(_hardware.Y || _hardware.X || _hardware.B){//only run this if the notch was adjusted
					//clean full cal points again, feeding updated angles in
					float cleanedPointsX[_noOfNotches+1];
					float cleanedPointsY[_noOfNotches+1];
					float notchPointsX[_noOfNotches+1];
					float notchPointsY[_noOfNotches+1];
					cleanCalPoints(tempCalPointsX, tempCalPointsY, notchAngles, cleanedPointsX, cleanedPointsY, notchPointsX, notchPointsY, notchStatus);
					//linearize again
					linearizeCal(cleanedPointsX, cleanedPointsY, cleanedPointsX, cleanedPointsY, _cStickParams);
					//notchCalibrate again to update the affine transform
					notchCalibrate(cleanedPointsX, cleanedPointsY, notchPointsX, notchPointsY, _noOfNotches, _cStickParams);
				}
			}else{//just show desired stick position
				displayNotch(currentCalStep, false, _notchAngleDefaults, _btn);
			}
			readSticks(false,true, _btn, _pinList, _raw, _hardware, _controls, _normGains, _aStickParams, _cStickParams, _dT, currentCalStep, false);
		}
	}
	else if(running){
		//if not calibrating read the sticks normally
		readSticks(true,true, _btn, _pinList, _raw, _hardware, _controls, _normGains, _aStickParams, _cStickParams, _dT, currentCalStep, currentlyRaw);
	}
}

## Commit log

2021-12-21 Added a bunch of functionality so that it actually reads buttons and stick inputs, verified things were working other than the triggers. The C stick seems to be rotated and reading strangely.
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2021-12-23 Got calibration routine working, curve fitting is not ideal yet. Need to store values to flash.
2021-12-24 Changed calibrate button to left d-pad, switched to 13 bit ADC, added eeprom storing of calibration coefficients.
2021-12-26 Added PCB design files
    [Board Outline.DXF, PhobGCC.kicad_pcb, PhobGCC.sch]
2021-12-26 Version of files sent to JLCpcb for manufacture, also uploaded to OSHpark
    [PhobGCC-B_Cu.gbl, PhobGCC-B_Mask.gbs, PhobGCC-B_SilkS.gbo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]
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2021-12-26 Trying again to get ready for removing unneeded kicad files
    [PhobGCC-B_Cu.gbl, PhobGCC-B_Mask.gbs, PhobGCC-B_SilkS.gbo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]
2021-12-26 Solving kicad file issues hopefully
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2021-12-29 Messy version of code, just got serialEvent() based communications working, should give reliable communications even with long main loop times. Will try implementing full kalman filter and clean up c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
2021-12-30 SerialEvent() wasn't reliable for some reason, went to straight interrupt based. Got Kalman working but need to think some more about the relationship between the damping and the variance parameters 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
2021-12-30 Changed the way the ADC variance changes with stick position a little bit, dashback and snapback look good with this controller
    [PhobGCC.ino]
2021-12-30 Changed schematic so that it "should" work with a teensy 3.2 or 4.0. Will require the pins of 2 of the d-pad buttons to be updated in the software.
    [PhobGCC.kicad_pcb, PhobGCC.sch]
2021-12-31 Added code for notch calibration, currently does not cause problems but havn't tried calibration yet. Need to implement saving the values to eeprom. If it works properly then almost all the intended 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
    [PhobGCC.ino]
2022-01-01 Got gate calibration working, but its not consistent because the gate positions are not super well defined, there's some slop in the stickbox, and the way the controller zero is found when dolphin st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
    [PhobGCC.ino]
2022-01-03 Added a few 3d models to the board CAD. Started commenting the code.
    [10118194c.step, PhobGCC.kicad_pcb, PhobGCC.step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]
2022-01-07 Changed pinout to match board made by jlc, these boards worked except that the usb data pads didn't line up. Something still wrong with affine transforms. Need to play around with filtering and PODE 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
    [PhobGCC.kicad_pcb]
2022-01-08 Working Code with JLC pcbs, has snapback filtering and gate calibration, need to clean up then will be ready for beta testing
    [PhobGCC.ino]
2022-01-10 Rewrote calibration functions to make them a bit more modular, implemented c-stick linearization and calibration as well. Everything seems to work ok, this version can be shared for people to try usi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
2022-01-10 Added use of bounce library to manage starting calibrations. Updated the schematic moving the c-stick connector to the bottom.
    [PhobGCC.kicad_pcb]
2022-01-12 Snapback adjustment and ZXY swapping seem to work, this is the version going out in the 002,003,004,005 boards
    [PhobGCC.ino]
2022-01-12 Added electronics BOM and put values in schematic
    [PhobGCC.sch]
2022-01-12 cap value assignment was wrong, fixed
    [PhobGCC.sch]
2022-01-12 and forgot to add the BOM, now added
    [DigiKey BOM.csv]
2022-01-12 Updated PCB to version 1.1, small fixes
    [PhobGCC.kicad_pcb]
2022-01-15 Updated layout so the LED pin doesn't get used, added link to wiki in readme.
    [PhobGCC.kicad_pcb, PhobGCC.sch]
2022-01-16 Found that the hall sensors dont scale their output with source voltage, leading to different values with small changes in Vcc. Used internal ADC reference to measure Vcc on start up and compensate.
2022-01-16 Changed the internal reference voltage check to update every loop. Changed the PCB to use a 2.5V regulator to power the hall effect sensors and pots as well as act as the ADC reference.
    [PhobGCC.kicad_pcb, PhobGCC.sch]
2022-01-21 Made it so that the serial frequency changes from 1000000 to 1250000 to respond to a command, this makes it appear to work with a wii u adapter.
    [PhobGCC.sch]
2022-01-23 Now also working with the Wii, had to decrease the latency of swapping the serial frequency back down, now triggers on the end of the response (as long as nothing goes wrong with the bit counting)
    [PhobGCC.ino]
2022-01-23 Made it so x and y snapback can be adjusted independantly on the analog stick
    [PhobGCC.ino]
2022-01-25 Converted PCB files to kicad v6, generated JLC manufacturing files for 1.1 version of the board, moved the old manufacturing files to the v1_20211226.rar file. Changed the way notch snapping is done,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
    [PhobGCC-B_Cu.gbl, PhobGCC-B_Mask.gbs, PhobGCC-B_SilkS.gbo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]
2022-01-29 Made reading the serial command more lenient, was reading C8 instead of E8 in particular causing issues. Hopefully communications is now sorted.
    [PhobGCC.ino]
2022-01-30 commit for v0.14 software tag with (hopefully) improved communication. Still issues with 4 controllers into a wii u adapter, but seems good otherwise.
    [PhobGCC.ino]
2022-02-05 Fixed issue with the linearization fit points, wasn't taking into account how the angles get projected in 3D properly before, giving incorrect values for the 45 degree positions. Started working on a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
    [PhobGCC.kicad_pcb]
2022-02-16 Lots of changes: Rewrote calibration code to allow for adjustable notches (changed eeprom layout for this), changed L and R zeroing to match standard controller, added snapback setting display
    [PhobGCC.ino]
2022-02-18 Fixed c-stick calibration
2022-02-24 Initial Push of AdvanceCal with A Button
    Functional but advances too quickly, requiring too quickly of an A-press. Will look into the timer function.
2022-02-28 cleaned manufacturing files for the v1.1 board
    [PhobGCC-B_Cu.gbl, PhobGCC-B_Mask.gbs, PhobGCC-B_Silkscreen.gbo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]
2022-03-10 Added a hysteresis constant for the analog stick to reduce jitter, also set notch calibration values to always be *.5 to make them equidistant from the surrounding values
    [PhobGCC.ino]
2022-03-10 Fixed an issue with setting the notch values to *.5, needed to be rounded to integer values so that when 127.5 is added they will have *.5 ... I think
    [PhobGCC.ino]
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2022-03-13 Filtering Adjustment Steps
    Filtering can now be adjusted in steps of 3 with the use of the Z-button
2022-03-26 Implement lighter-weight Kalman filter (#15)
    * Implement lighter-weight Kalman filter
    It should both run faster and be more responsive to small stick inputs.
    It's faster because I removed all the unnecessary matrix math.
    * fix kalman timestep unit
    * add explanation for kalman posWeight
    * clean up timestep calcs a bit
    * make it compile
    * fix struct instantiation syntax
    * Slight optimization by precomputing inverses
    Maybe the compiler would have done this, maybe not. I think that
    inverses in particular are faster than normal old divison...
    [PhobGCC.ino]
2022-03-26 Remove integral correction from kalman filter
    It did essentially nothing at all in the end.
    [PhobGCC.ino]
2022-03-27 Fixing Notch Adjustment
    Loop was running so fast that loopDelta was getting truncated to 0. changed it to float.
    [PhobGCC.ino]
2022-03-27 Adjusting Snapback now works with the new filter
    [PhobGCC.ino]
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2022-03-29 Remove Snapback Adjustment Granularity
    Removing the +3 snapback adjustment granularity and code cleanup to bring it in-line with boardv1.1
    [PhobGCC.ino]
2022-03-31 Move hardware-specific code into separate header files (#27)
    * Split up hardware-specific code into headers
    This lets us have the firmware for multiple hardware revisions in the
    same branch.
    * update gitignore for vim swp
    * add vref start to board 1.0
2022-04-02 Implemented a fixed timestep currently set to 1kHz, averaging analog stick values during the idle time, added hysteresis back in to see how stable it can be
    [Phob1_0Teensy3_2.h, Phob1_1Teensy3_2.h, PhobGCC.ino]
2022-04-02 Implement 3 to 5-tap moving median filter (#30)
    * implement median filter
    * make it easier to turn median on and off
    * fix 5-tap median
    * default the median filter off
    * fix comment for median
    [PhobGCC.ino]
2022-04-02 Included the 3 tap median filter and adjusted accelThresh down to 0.1 to compensate
2022-04-02 Fixed velThresh back to 1.0
    [PhobGCC.ino]
2022-04-03 Added median filter to the calibration process to account for any offset it causes
2022-04-03 Moved median filter after kalmanish filter to prevent acceleration threshold issues
    [PhobGCC.ino]
2022-04-05 add teensy4 support (#31)
    works for the board 1.1 teensy for mod with diode
2022-04-09 C-stick Offset + SafeMode + Harder To Reset (#29)
    * C-stick Offset + SafeMode + Harder To Reset
    C-stick Offset can now be adjusted using the X or Y button to define the Axis, A to increase or B to decrease. Controller now has a safe mode, Dpad Down + Start is necessary to configure anything. Reset is now harder to input, Start+Dpad Left.
    * Restructed Safemode and Fixed C-stick offset Interfering with Z-jump
    [PhobGCC.ino]
2022-04-09 Removed all hardware files, will be moved to the hardware repo. Updated serial print message for 0.18 tag.
    [10118194c.step, Board Outline.DXF, DigiKey BOM.csv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]
2022-04-12 Made it so that the median only gets used during calibration if its defined
2022-04-13 moved setPole into the communication code... could be spikes are caused by running the communication interrupt while setPole was running?
2022-04-13 Played with readsticks a bit so it doesn't get messed up during calibration.
    [PhobGCC.ino]
2022-04-13 Reset the board selection comment
    [PhobGCC.ino]
2022-04-15 Add smoothing function for single-motion ledgedash
    It is only hardcoded for now, so after testing it needs UI implemented.
2022-04-15 fix some dumb typos in recomputeGains
    [PhobGCC.ino]
2022-04-20 Control UI overhaul
    Implemented the Rienne-style commands for PhobGCC configuration. All Sticks freeze when changes occur. C-stick Offset now displays the coordinate output when changed or allows for the current state to be checked. Also set up a safety check so that the user can't set it too high.
    [PhobGCC.ino]
2022-04-20 Added header file for board version 1.2 with rumble, various fixes
    [Phob1_2Teensy4_0.h, PhobGCC.ino]
2022-04-22 Skip Debouncing And Poll Pins Directly
    [PhobGCC.ino]
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2022-04-29 Calibration Trigger Mapping
    Swapped Analog Trigger Calibration Mapping, Increased adjustNotch value a hair.
    [PhobGCC.ino]
2022-04-29 Calibration Advancement and Ledgedash Typo Fixes
    Calibration now advances with L/R and undoes with Z. Also fixed a typo that made ledgedash delay break snapback.
    [PhobGCC.ino]
2022-05-03 Fixed the rumble pins and set them to outputs
    [Phob1_2Teensy4_0.h, PhobGCC.ino]
2022-05-03 Corrected the queue lengths (were off by one after removing the stop bits from _commResponse and _probeResponse
    [PhobGCC.ino]
2022-05-05 further fix attempts, plus serial debug out for phobos
    [PhobGCC.ino]
2022-05-05 States 0,1, 2 Trigger Rework Implemented
    [PhobGCC.ino]
2022-05-06 fix new notch adjust
    [PhobGCC.ino]
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2022-05-06 comment out notch adj skipping for c stick
    [PhobGCC.ino]
2022-05-06 fix undoing calibration, hopefully
    [PhobGCC.ino]
2022-05-08 fix full notch calibration
    [PhobGCC.ino]
2022-05-08 fix advance/undo for notch adjust
    [PhobGCC.ino]
2022-05-08 make start skip to notch adjustment
    [PhobGCC.ino]
2022-05-10 FreezeSticks Time Parameter
    Freezesticks now takes a parameter in milliseconds for how long to freeze. Freezes also point to the top right.
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2022-05-12 add c-stick smoothing for snapback
    [PhobGCC.ino]
2022-05-18 replace 127.5s with 128 for proper zero
    [PhobGCC.ino]
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2022-05-29 Adding in origin snapping
    [PhobGCC.ino]
2022-05-29 resolve rx pin stuff
    [PhobGCC.ino]
2022-05-29 Revert "removing Press B to Initialize"
    This reverts commit def606f6de1c1f0e1bf546e5ca46d0e9d36da1f8.
    [PhobGCC.ino]
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2022-05-30 revert safe mode toggle command
    [PhobGCC.ino]
2022-05-31 Created _pinInt variable in the headers, used this instead of _pinRX to specify which pin is used for the communication interrupt trigger. Using the RX pin for the interrupt doesn't for a teensy 4.0 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
    [Phob1_0Teensy3_2.h, Phob1_1Teensy3_2.h, Phob1_1Teensy4_0.h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]
2022-05-31 Fix rumble eeprom loading
    [PhobGCC.ino]
2022-06-07 Added stop bit to probe response, added readsticks and readbuttons in setup before starting comms to ensure trigger data is ready when the connection is made
2022-06-07 Fixed inputs to readSticks in setup
    [PhobGCC.ino]
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2022-06-08 Changed how _running is used so that it is checked before calling readsticks. The button object is now initialized during setup to set the zero positions for the sticks and triggers. They should stay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
2022-06-13 enable disabling of the main snapback filter
    [PhobGCC.ino]
2022-06-14 fix lowpass filter on main stick
    [PhobGCC.ino]
2022-06-18 Adjusted _maxStickAngle from 38.5 to 28 degrees (made a mistake in the initial calculation), also removed the seperate default calibration values for the analog and C stick now that most people will 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
    [PhobGCC.ino]
2022-06-28 cleaned up and commented the communication code for the teensy 3.2 a bit
2022-06-28 Added the board header files to the repository and a little bit of tidying
2022-07-02 add phob1.1t3.2 diode short include line
    [PhobGCC.ino]
2022-07-04 fix analog stuff for teensy 4
    [PhobGCC.ino]
2022-07-05 fixed comment referring to 1.1 instead of 1.2
    [Phob1_2Teensy4_0.h]
2022-07-09 make zjump config swap back if repeated
    [PhobGCC.ino]
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2022-07-16 Increased the fast baudrate for t4.0 from 2.5MHz to 2.6MHz to allow for 2kHz polling in smashscope, decreased the serial reset timer to match
    [PhobGCC.ino]
2022-07-17 auto-hard-reset on initial boot
    [PhobGCC.ino]
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2022-07-19 bump version number for the reset-initially branch
    [PhobGCC.ino]
2022-08-10 weaken the minimimum snapback suppression
    [PhobGCC.ino]
2022-08-10 Implement an auto-initialization feature
    First off, I made the reset function work for both hard and soft resets.
    Soft resetting doesn't change the stick calibration, but it does reset
    filtering params, button swaps, and trigger configurations.
    Hard resetting does everything including sticks.
    The old reset command is now soft reset, and the new hard reset command
    is ABZ+Dd.
    Next, I made a shortcut (LRXY+Start) to make the controller
    auto-initialize on plugging in.
    This gets canceled whenever you perform a calibration, or do a hard
    reset.
    [PhobGCC.ino]
2022-08-13 make soft reset cancel auto init
    [PhobGCC.ino]
2022-08-14 fix comms to slower baudrate
    [PhobGCC.ino]
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2022-09-17 add snapback to the controls struct
    [PhobGCC.ino]
2022-09-21 fix dT in readSticks
    [PhobGCC.ino, stick.h]
2022-09-25 add snapback and smoothing to settings.h
    [PhobGCC.ino, settings.h]
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2022-10-02 fix teensy 3.2 compilation
    [comms.h, phobGCC.h]
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2022-10-05 Add toggle/config separation, currently bugged
    [phobGCC.h]
2022-10-06 Fix bug preventing setting Extras configs
    [phobGCC.h]
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2022-10-10 fix mode 5 triggers
    [phobGCC.h]
2022-10-11 correct the numberofnan limit
    [PhobGCC.ino]
2022-10-12 fix waveshape multiplier calculation
    [filter.h]
2022-10-15 Right Trigger Typo Fixes
    [phobGCC.h]
2022-10-15 Fix cstick notch angle loading
    [phobGCC.h]
2022-10-15 remove broken stuff from phob1.0 header
    [Phob1_0Teensy3_2.h]
2022-10-16 Revert "Re-writing Mode 7"
    This reverts commit 726fbebd302ce808a3d4bb5e6fe58f054bea95ab.
    [phobGCC.h]
2022-10-16 make hard reset a long press
    [phobGCC.h]
2022-10-18 Fix show right stick settings in commands comment
    [phobGCC.h]
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2022-10-23 fix capitalization in rp2040 settings
    [phobGCC.h]
2022-10-23 fix more settings capitalization
    [phobGCC.h, settings.h]
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2022-10-30 Snapping no longer occurs during calibration
    [PhobGCC.ino, main.cpp, phobGCC.h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]
2022-10-30 fix timestep calculation (why didn't it work)
    [phobGCC.h]
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2022-11-07 images and text work, lines don't seem to?
    if there's too much at once it starts flickering or something
    [cvideo.h]
2022-11-12 1khz adc plus video works at the same time!?!?!?!
    why
    I don't get it
    why didn't it work before, why is it working now
    [Phob2_0.h, cvideo.h, main.cpp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]
2022-11-13 add back in missing dpad pins
    [Phob2_0.h]
2022-11-13 it seems to work but the stick won't calibrate
2022-11-15 fixed the freezing after 2^32 us on teensy
    [Phob2_0.h, PhobGCC.ino, cvideo.h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]
2022-11-16 make comms respond faster, fix teensy filter
    [joybus.cpp, main.cpp, phobGCC.h]
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2022-11-22 Revert "make comms respond faster, fix teensy filter"
    This reverts commit 32ab8e2fa3150d35eb7809aae3261c046a190f3e.
    [cvideo.h, main.cpp]
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2022-11-26 make the lower case a shorter
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2022-12-09 Add protoboard file and readHardware, fix pins
    It doesn't work on the phob board for some reason, even the same binary
    that runs on a pico.
    [Phob2_0.h, PicoProtoboard.h, readHardware.h]
2022-12-10 now it runs, but storage doesn't write
    [main.cpp, phobGCC.h]
2022-12-18 fix lras in configure mode
    [phobGCC.h]
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2022-12-24 why doesn't it work
    [main.cpp, phobGCC.h]
2023-01-07 fix glitches on oem?
    [joybus.cpp, main.cpp, phobGCC.h]
2023-01-07 more thorough fix for oem adapter
    [joybus.cpp]
2023-01-07 fix notch adjust bug
    [PhobGCC.ino, main.cpp, phobGCC.h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]
2023-01-09 set cardinal snapping to 6
    [stick.h]
2023-01-13 Initial Stick Toggles Commit
    Builds in Analog Scaling and Cardinal Snaping Behavior.
    Note: Cardinal Snapping is not yet applied.
    [phobGCC.h, settings.h]
2023-01-13 Fixed Rebasing Issues
    Rebased the branch off of latest main (42 commits ahead) and overlapped with existing code, this fixes it.
    [phobGCC.h]
2023-01-13 Compilation Fixes
    Fixes typos to ensure compilation for teensy and rp2040
    [phobGCC.h, settings.h]
2023-01-14 Correcting Storage settings, commands, and finishing cardinal snapping
    [phobGCC.h, stick.h]
2023-01-14 Making Cardinal Snapping Stick-Independent
    [phobGCC.h, stick.h]
2023-01-14 Fixing Analog Scaling and Overlapping Commands
    [phobGCC.h]
2023-01-14 Fix Astick commands overlapping with Cstick ones
    [phobGCC.h]
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2023-03-11 fix copypaste error and remove testing thing
    [filter.h]
2023-03-11 shorten safe mode toggle duration
    [phobGCC.h]
2023-03-11 revise hard reset lockout duration
    [phobGCC.h]
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2023-03-15 add explanation for negative snapback
    [menuStrings.h]
2023-03-15 cardinal snapping menu done
    [menuStrings.h]
2023-03-16 tweak cardinal snapping, remove coffset
    [phobGCC.h, stick.h]
2023-03-17 fix rounding for cardinals
    [stick.h]
2023-03-17 Revert "Dev tournament toggle"
    [phobGCC.h, settings.h]
2023-03-18 shorten tourney mode delay to 1s
    [menuStrings.h, phobGCC.h]
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2023-03-29 shorten repeat time for button press viewer
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2023-04-25 snapback and dashback % work
    [main.cpp, menuStrings.h]
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2023-06-03 re-migrate cardinal stick snapping
    [phobGCC.h]
2024-03-08 fix showsticksettings for negative waveshaping
    [phobGCC.h]
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2024-03-16 0.84 soft cardinal avoidance
    [menuStrings.h, phobGCC.h, stick.h]
2024-04-16 fix second cal first step
    [phobGCC.h]
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2024-04-23 fix negative waveshaping accel sensitivity
    [filter.h]
2024-05-03 change default snapback for cstick
    [phobGCC.h]
2024-05-04 fix sub-byte order in mode structs
    [gcReport.hpp, joybus.cpp]
2024-05-31 fix trigger analog lockout
    [phobGCC.h]
2024-06-02 add remap reset, fix trig analog lockout
    [phobGCC.h]
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2024-09-12 remove mode 5 conflict, mode 4 ult fix
    [menuStrings.h, phobGCC.h]
2024-10-03 make resetting reset tourney toggle
    [phobGCC.h]
2024-10-23 fix rumble braking on phob2, remove option
    [comms.h, joybus.cpp, main.cpp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]
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2025-11-14 fix trigger settings output command
    [phobGCC.h]
